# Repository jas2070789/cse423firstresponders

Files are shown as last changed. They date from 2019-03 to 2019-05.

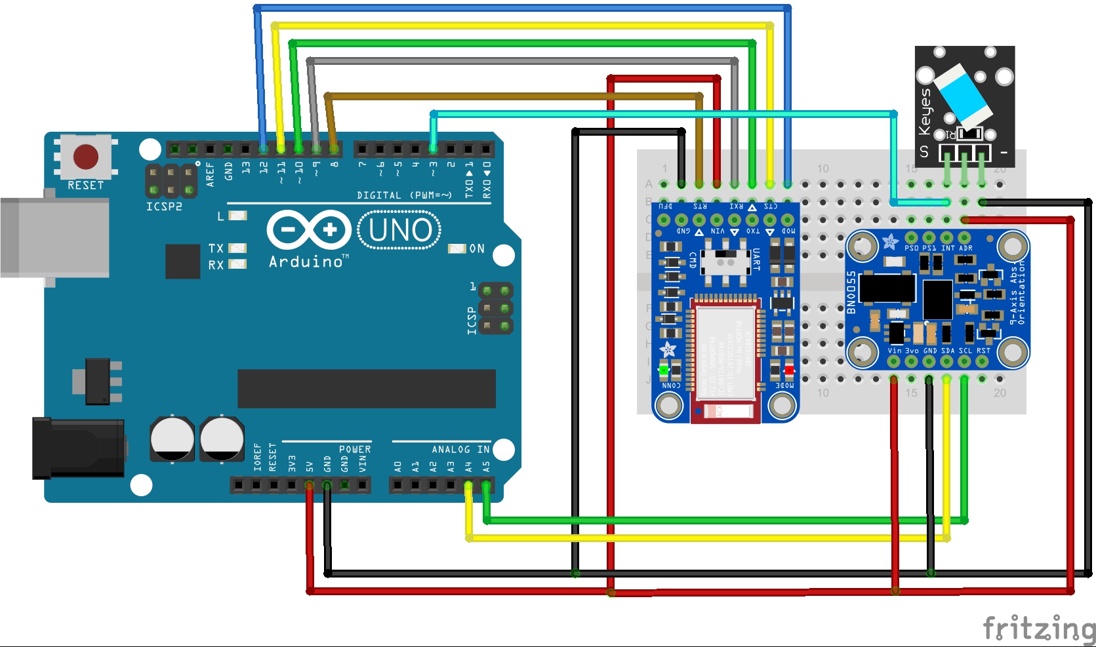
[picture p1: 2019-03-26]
FRONTEND/Wearable_Schematic_bb.jpg

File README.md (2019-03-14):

# CSE423/424 ASU Capstone - Benchmark: First Responder Tracking System
#### Members: Patrick Archer, Joshua Owens, Haoyu Xu, Jason Zellers

## Motivation
Firefighters and first responders commonly experience uncontrolled chaos on their jobs as they rush into dangerous environments to save lives and property. Many frequently navigate buildings and areas with poor visibility and accessibility with little general awareness of their surrounding squadmates. ***Existing methods of tracking firefighter location provide little to no usable or reliable data. This puts firefighters in a great amount of risk.*** Additionally, without real-time knowledge of first responder locations, command central encounters great difficulty in trying to direct personel throughout a scene. For example, directing a squad towards the last known location of a civilian essentially only entails verbal directions via radio. This is not nearly reliable or efficient enough for use by individuals trying to traverse a dangerous environment in a limited amount of time.

***The goal of this project is to provide real-time X, Y, and Z-axis locations for individual on-scene first responders without the use of GPS or an internet connection.***
Improved methods of tracking first responder location would promote safety by providing constant and reliable information regarding individual locations in real-time. Promoting better coordination and teamwork on the job by providing accurate location data would allow first responders to minimize the potential risk to their lives and the lives of civilians in need.

This system is not to be entirely specific to firefighters. It is capable of being utilized by other types of first responders, such as law enforcement and EMS. Coordination and hyper-awareness of every detail on the scene is critical to ensure the safety of everyone involved.  For example, when police or SWAT are actively securing an area, knowledge of the exact count of officials on a scene and where their precise locations are in X,Y, and Z-axes is massively beneficial.

## For more information, please refer to the [Comprehensive Technical Documentation](https://docs.google.com/document/d/1ydmMYP7WzZiBYYO7bbs8z_xTuEj2Cn52D5nfCjR_mMc/edit?usp=sharing).

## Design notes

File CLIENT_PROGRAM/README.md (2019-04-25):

# Overview of "CLIENT" Sub-System

*Note: By default, the Client device needs to use an IPv4 address of ```10.0.2.255``` unless altered otherwise in source code.*

This sub-system encompasses everything required to develop a software program that can 1) join the WADHOC network, 2) query up-to-date location data, and 3) present queried data to a user via a terminal.

After configuring the device to communicate with the WADHOC network, a user will run a custom program that accesses the Central Hub's database. This program utilizes Python socket-level network programming to communicate with the Central Hub and perform database queries via a custom API interface.

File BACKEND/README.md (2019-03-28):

# Overview of "Back-End" Sub-System

The “back-end” sub-system consists of any number Anchor devices, one Central Hub ("CH") device, and a client machine that queries location data from the CH. These devices are all connected to a peer-to-peer Wireless Ad-Hoc network ("WADHOC").

The Anchor nodes communicate with other Anchors as well as the CH via the WADHOC using Python socket shell scripting. 

The CH will process all data incoming from the Anchors, which are constantly forwarding data regarding the Mobile Wearable Beacon ("MWB") devices. Data parsing and calculations are performed entirely by the CH. The CH will act as a single point of access for the most up-to-date location information. As such, the client machine's query program will be directly accessing the CH's database.

The client machine is a laptop ideally running the Ubuntu 18.04 64-bit operating system. This client machine needs to physically be within-range of the WADHOC in order to connect to the network. This is because the CH and Anchor devices are not actually connected to the internet; all communication between devices is entirely local via the WADHOC. The client will use a program to perform data queries. The program will be written in Python v3.0+ with an initial interface in command shell (a GUI may be implemented in a later release). Query data will be in regards to the X, Y, and Z-axis locations of the MWB devices being carried by first responders.

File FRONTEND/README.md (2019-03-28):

# Overview of "Front-End" Sub-System

The front-end sub-system describes the functionality Mobile Wearable Beacon ("MWB") devices alongside the Anchors. The front-end subsystem entirely communicates via Bluetooth-Low-Energy ("BLE"), contrary to the back-end sub-system which communicates via Wireless Ad-Hoc ("WADHOC").

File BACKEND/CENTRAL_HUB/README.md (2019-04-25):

# Overview of "CENTRAL HUB" Sub-System

*Note: By default, the Central Hub device needs to use an IPv4 address of ```10.0.2.1``` unless altered otherwise in source code.*

This sub-system encompasses everything regarding Central Hub operations.

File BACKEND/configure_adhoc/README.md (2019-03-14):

# Configuring a Raspberry Pi's Wireless Network Interface to Connect to WADHOC Network

###### Target Operating System: Raspbian Stretch (Full) v.2018-11-13

***Raspbian Stretch changed much of the networking setups and protocols that were used in previous builds "Wheezy" and "Jessie". As a result, in order to actually set up a Wireless AD-HOC ("WADHOC") network, a few of those changes will need to be bypassed. This README details how to accomplish this.***

For each device that needs to connect to the WADHOC network, `/etc/dhcpcd.conf` and `/etc/network/interfaces` must be modified. When configuring the WADHOC on subsequent devices, the values for certain parameters will need to be changed accordingly. These changes will be discussed in detail further in this document.

*The following information represents what would have to be done to configure the Central Hub device.*

The `/etc/network/interfaces` file has been made obsolete in favor of `/etc/dhcpcd.conf`. However, for a simple ad-hoc network, we have no need to utilize a DHCP server, since the Pis only need to be able to talk to each other. We need to stop the Pi from automatically configuring its wireless interface to its default value. We do that by adding the following command to the top of `/etc/dhcpcd.conf`:

```
denyinterfaces eth0 wlan0
```

*Note: This is assuming the only network interfaces active on the RPi are eth0 and wlan0. If there are more, they must be appended to this command. It is crucial that the wireless interface being used to configure the ad-hoc connection is denied (in this case, wlan0). Use `sudo iwconfig` to query a list of the device's network interfaces. Do not deny the `lo` (loopback) interface.*

The above command tells the RPi that it shouldn’t configure its network interfaces via `/etc/dhcpcd.config` and it should instead configure via `/etc/network/interfaces`.

We then add the following parameters to the `/etc/network/interfaces` file:

```
auto wlan0
iface wlan0 inet static
  address 10.0.0.1
  netmask 255.255.255.0
  wireless-channel 1
  wireless-essid ADHOCTEST
  wireless-mode ad-hoc
```
  
The value for the address will change depending on what node is being configured. 10.0.0.1 will always belong to the Central Hub, however for each Anchor the address needs to be incremented in the /24 subnet (so Anchor1 = 10.0.0.2, A2 = 10.0.0.3, etc.). The netmask, wireless-channel, essid, and mode all remain the same.

After saving the file, restart the device for changes to take full effect. Upon next boot, the device's wlan0 interface will be connected to the "ADHOCTEST" network.

**This process must be repeated for every other node that wants to connect to the WADHOC. The address and (if necessary) the target interface are to be modified, however most other values MUST remain the same (ESSID, channel, netmask, and mode).**

For example, this is what an Anchor device must modify in the two files:

- In /etc/dhcpcd.config:
```
denyinterfaces eth0 wlan0
```

- In /etc/network/interfaces (*note the different address compared to the Central Hub*):
```
auto wlan0
iface wlan0 inet static
  address 10.0.0.2
  netmask 255.255.255.0
  wireless-channel 1
  wireless-essid ADHOCTEST
  wireless-mode ad-hoc
```

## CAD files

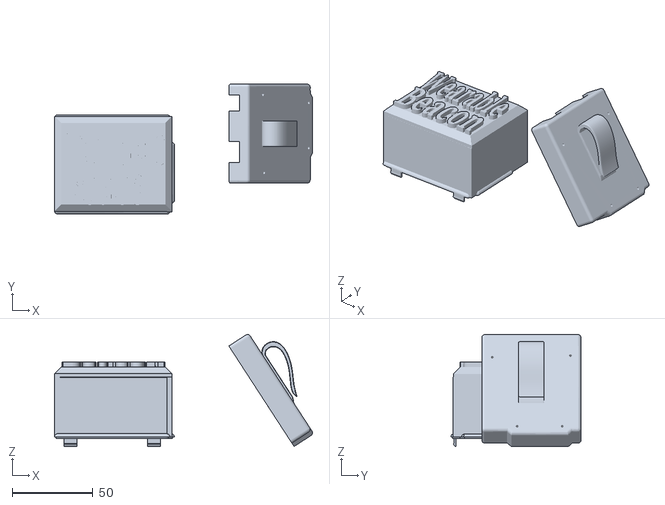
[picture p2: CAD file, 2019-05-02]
FRONTEND/Wearable Bottom Case.stl
159.5 x 80.4 x 69.3

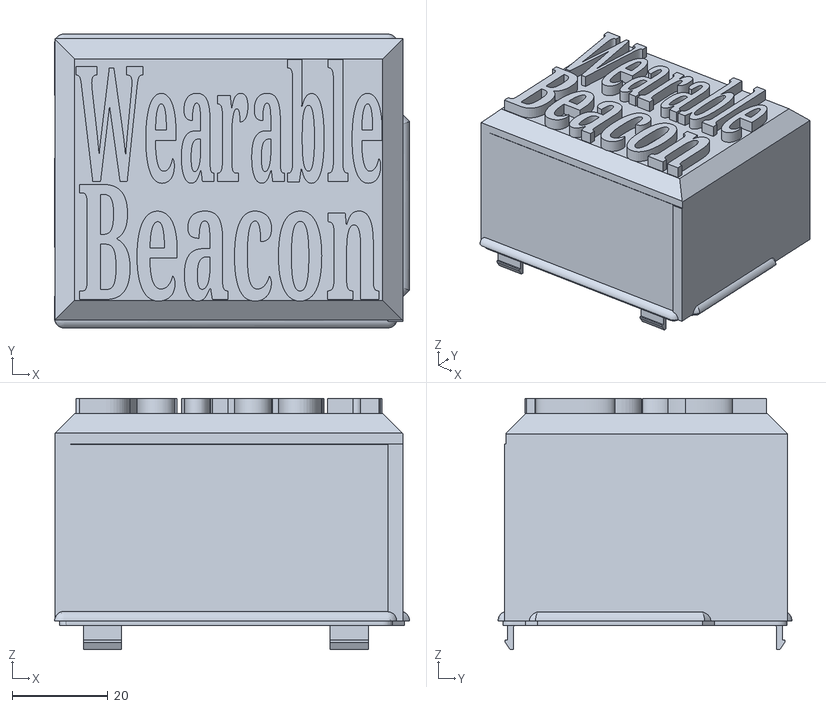
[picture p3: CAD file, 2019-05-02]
FRONTEND/Wearable Top Case/tinker.obj
74.1 x 61.3 x 52.4

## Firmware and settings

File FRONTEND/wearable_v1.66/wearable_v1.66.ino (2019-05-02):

/*
   Connections - BNO055
   ===========
   Connect SCL to analog 5
   Connect SDA to analog 4
   Connect VDD to 3.3V DC
   Connect GROUND to common ground

   Connections - KY-017 - tilt switch
   ===========
   +----------+
   |          |
   |          | - S - D3
   |          | - Power (5v)
   |          | - G - ground
   |          |
   +----------+

   History
   =======
   02/25/19  - V 1.0
   03/21/19  - V 1.5
        Changes:  Added tilt switch
                          Accelorometer from IMU had calibration issues
                  Added quadrant tracking
                  Added pedometer functionality
                  Added string builder (what gets sent over BLE

    03/22/19 - V 1.6
        Changes:  Added BLE Services
                  TODO: Test Services on PI
                  
        TODO:     Add junk calibration validation (if calibration = 0 dont accept data)
                  Add warning light if hard reset is required
                  Verify ArrayFull Functionality
*/

#include <Wire.h>
#include <Adafruit_Sensor.h>
#include <Adafruit_BNO055.h>
#include <utility/imumaths.h>

#include "Adafruit_BLE.h"
#include "Adafruit_BluefruitLE_SPI.h"
#include "Adafruit_BluefruitLE_UART.h"

#include "BluefruitConfig.h"

#if SOFTWARE_SERIAL_AVAILABLE
  #include <SoftwareSerial.h>
#endif

#define BNO055_SAMPLERATE_DELAY_MS (500)
// FROM ONLINE GUID GENERATOR -> define GUIDs for BLE service & characteristic
#define WEARABLE_SERVICE_UUID128  "d9-bd-9b-0e-da-5e-42-de-90-cf-54-5c-7d-17-19-12"
#define WEARABLE_STR_CHAR_UUID128 "45-98-FB-6C-F5-6B-40-28-AD-27-E3-F7-AA-14-89-1F"
#define PACKET_LENGTH 10   // Define the length of a packet (in bytes)   
#define PACKET_ARRAY_LENGTH 50  // Define in multiples of 5                       

Adafruit_BNO055 bno = Adafruit_BNO055(55);

/********************************************************************/
float heading = 0;
int quad = 0; // break 360 degree heading into 4 quadrants
String imuData; // Map FP compass heading & step count
boolean quadChange = false; // track if the quadrant # has changed -> concat step count to string

// Step Count (Pedometer Variables)
int tiltSwitch = 3; // Tilt Switch Input
int tiltVal = 0; // variable to store tilt input
int tiltOldVal; // tilt last state
int stepCount = 0; // state change iterator

// Quadrant Builder Variable
String empID = "001"; // track employee ID    
String buffPacket;
int oldQuad;  //track state change
int count = 0; // placeholder to iterate through packetBuilder
int packetNumber = 0;   // So the gateway can place packet in correct order within the file

// STRTX() variables
int transmit;          // In order to ensure proper packet data exists within IMU data string
int maxTransmit = 5;
boolean arrayEmpty = false;
boolean transmitSuccess = false;

/* The BLE service information */
int32_t wearServiceId;
int32_t wearStringCharId;
boolean success;
//char buff[PACKET_LENGTH];        // Used to iterate through IMU data and place in <UUID><PacketNum><quad><setCount> sequence
String packetBuilder;
String packetData[PACKET_ARRAY_LENGTH]; // Store IMU data into packets-> iterate through array to send over BLE

SoftwareSerial bluefruitSS = SoftwareSerial(BLUEFRUIT_SWUART_TXD_PIN, BLUEFRUIT_SWUART_RXD_PIN);

Adafruit_BluefruitLE_UART ble(bluefruitSS, BLUEFRUIT_UART_MODE_PIN,
                      BLUEFRUIT_UART_CTS_PIN, BLUEFRUIT_UART_RTS_PIN);



/********************************************************************/

void error(const __FlashStringHelper*err) {
  Serial.println(err);
  while (1);
}

void ReadHeading() { // Output: HEADING
  imu::Vector<3> euler = bno.getVector(Adafruit_BNO055::VECTOR_EULER);
  heading = (float)euler.x();
  heading -= 90; // Adjust for IMU orientation

  if (heading < 0 ) {
    heading = 360 + heading;
  }

  if (heading > 360) {
    heading = heading - 360;
  }
  //Serial.print("Heading: \t");
  //Serial.println(heading);
}

void quadrantBuilder() {
  oldQuad = quad;
  count = 0;
  packetBuilder = empID;
  packetBuilder += "|";
  tiltOldVal = tiltVal;

  if (0 < heading && heading < 90) {
    quad = 1;
  } else if (91 < heading && heading < 180) {
    quad = 2;
  } else if (181 < heading && heading < 270) {
    quad = 3;
  } else if (271 < heading && heading < 360) {
    quad = 4;
  } 

  tiltVal = digitalRead (tiltSwitch) ;// read the switch value
        
  if (tiltVal != tiltOldVal) //Step State changed
  {
    stepCount++;
  }
  
  if (oldQuad != quad) {  //Quadrant state change -> new course detected!
    imuData += oldQuad;
    imuData += "|";
    imuData += stepCount;
    imuData += "|";
    stepCount = 0;

    //build BLE Packet
    Serial.print("Packet Number: ");
    Serial.println(packetNumber);
    packetBuilder += packetNumber;
    packetBuilder += "|";
    packetBuilder += imuData;

    Serial.print("imuData length: ");
    Serial.println(imuData.length());
    // parse through packetbuilder to place in packet array data
    while (imuData.length()>0){
      
      //.getBytes(buff,PACKET_LENGTH)
      String str = packetBuilder.substring(0,PACKET_LENGTH);
      packetData[packetNumber] = str; 
     
      // delete last packet
      packetBuilder = packetBuilder.substring(PACKET_LENGTH);

      // iterate for next packet 
      imuData = imuData.substring(PACKET_LENGTH);
      packetNumber+=1;
      if (packetNumber>PACKET_ARRAY_LENGTH+2){
        fullPacketArray();
      }
      count += PACKET_LENGTH;
    }
  }

    //set BLE packet to array
//    packetData[packetNumber] = buffPacket;

  // Serial.print("Quadrant: \t");
  //Serial.println(imuData);
}

void imuStatus() {
  /* check calibration data for each sensor. */
  uint8_t system, gyro, accel, mag;
  system = gyro = accel = mag = 0;
  bno.getCalibration(&system, &gyro, &accel, &mag);
  Serial.print(F("Calibration: "));
  Serial.print(system, DEC);
  Serial.print(F(" "));
  Serial.print(gyro, DEC);
  Serial.print(F(" "));
  Serial.print(accel, DEC);
  Serial.print(F(" "));
  Serial.println(mag, DEC);
}

//void StrTX(){
//  delay(1000);
// // memset(buff,0,sizeof(buff));    //initialize buffer to 0
//  
////  if (count<str.length()){
////    //str.substring(count,count+PACKET_LENGTH).getBytes(buff,PACKET_LENGTH);
////    Serial.print("Buffer: ");
////    Serial.println(buff);
////    Serial.print("string: ");
////    Serial.println(str);
////
////    setCharacteristic(wearTXCharId, buff);
////    
////  }
//
//    Serial.print("transmit: ");
//    Serial.print(transmit);
//    Serial.print("\tmaxTransmit: ");
//    Serial.println(maxTransmit);
//        Serial.print("\tpacketData: ");
//        Serial.println(packetData[transmit]);
//
//    if (packetData[transmit].length()==0){   //end of data in array
//      Serial.println("empty ARRAY");
//      transmit = 0;
//      maxTransmit = 5;
//      arrayEmpty = true;
//      }
//      
//    if (maxTransmit >= PACKET_ARRAY_LENGTH) {
//      Serial.println("FULL ARRAY");
//      transmit = 0;
//      maxTransmit = 5;
//      int halfArray = floor(0.5*PACKET_ARRAY_LENGTH);
//      int j = halfArray;
//      for (int i = 0; i<halfArray; i++) {
//        packetData[i]=packetData[j];
//        packetData[j]= "";
//        j++;
//      }
//    }  
//    
//    int localCounter = transmit;  
//    while ((localCounter < maxTransmit) && (!arrayEmpty)) {
//          setCharacteristic(wearStringCharId, packetData[localCounter]);
//          localCounter++;
//    }
//    Serial.println("Increment");
//    transmit= transmit+ 5;
//    Serial.println("Increment 2");
//    maxTransmit=maxTransmit+5;
//    arrayEmpty = false;
//    
//    
//}

void StrTX(){
  int localCount=transmit;

  if(packetData[transmit].length() == 0  || packetData[transmit+1].length() == 0 || packetData[transmit+2].length() == 0
                                           || packetData[transmit+3].length() == 0 || packetData[transmit+4].length() == 0){
      arrayEmpty = true;
      transmit=0;
      maxTransmit=5;
      
    }
    
  while((maxTransmit<PACKET_ARRAY_LENGTH) && (!arrayEmpty) && localCount < maxTransmit) {
    Serial.print("localCount: ");
    Serial.println(localCount);
    setCharacteristic(wearStringCharId, packetData[localCount]);
    localCount++;
    transmitSuccess = true;
  }

  if (transmitSuccess) {
    transmit+=5;
    maxTransmit+=5;
  }

  if (maxTransmit >= PACKET_ARRAY_LENGTH+5) {
      fullPacketArray();
  }
  arrayEmpty = false;
  transmitSuccess = false;
  Serial.print("transmit: ");
  Serial.print(transmit);
  Serial.print("\tmaxTransmit: ");
  Serial.println(maxTransmit);
}
void fullPacketArray(){
    Serial.println("FULL ARRAY");
//    int a = 0;
//    for (a=0; a < PACKET_ARRAY_LENGTH; a++) {
//      Serial.println(" ARRAY BEFORE");
//      Serial.print(a);
//      Serial.print(": ");
//      Serial.println(packetData[a]);
//    }
    transmit = 0;
    maxTransmit = 5;
    packetNumber = 0;
    int halfArray = floor(0.5*PACKET_ARRAY_LENGTH);
    int j = halfArray;
    for (int i = 0; i<halfArray; i++) {
      packetData[i]=packetData[j];
      packetData[j]= "";
      j++;
    }

//    int b = 0;
//    for (b=0; b < PACKET_ARRAY_LENGTH; b++) {
//      Serial.println(" ARRAY AFTER");
//      Serial.print(b);
//      Serial.print(": ");
//      Serial.println(packetData[b]);
//    }
}
void setCharacteristic(int32_t charId, String str){
  ble.print(F("AT+GATTCHAR="));
  ble.print(charId,DEC);
  ble.print(F(","));
  ble.println(str);
  if (!ble.waitForOK()){
    Serial.println(F("Failed to get a response"));
  }

 // str = empID + "|";
  
}

/********************************************************************/
void setup() {
  Serial.begin(9600);
  if (!bno.begin())
  {
    /* There was a problem detecting the BNO055 ... check your connections */
    Serial.print("Ooops, no BNO055 detected ... Check your wiring or I2C ADDR!");
    while (1);
  }
  //  imuStatus();
  pinMode (tiltSwitch, INPUT) ;// define the mercury tilt switch sensor output interface

  if ( !ble.begin(VERBOSE_MODE) )
  {
    error(F("Couldn't find Bluefruit, make sure it's in CoMmanD mode & check wiring?"));
  }
  Serial.println( F("OK!") );
   /* Perform a factory reset to make sure everything is in a known state */
  Serial.println(F("Performing a factory reset: "));
  if (! ble.factoryReset() ){
       error(F("Couldn't factory reset"));
  }

  /* Disable command echo from Bluefruit */
  ble.echo(false);

  Serial.println("Requesting Bluefruit info:");
  /* Print Bluefruit information */
  ble.info();

  // this line is particularly required for Flora, but is a good idea
  // anyways for the super long lines ahead!
   ble.setInterCharWriteDelay(5); // 5 ms

  /* Change the device name to make it easier to find */
  Serial.println(F("Setting device name to 'wearable': "));

  if (! ble.sendCommandCheckOK(F("AT+GAPDEVNAME=Wearable")) ) {
    error(F("Could not set device name?"));
  }

  /* Add the Wearable Service definition */
  /* Service ID should be 1 */
  Serial.println(F("Adding the Wearable Service definition (UUID = 0x180D): "));
  success = ble.sendCommandWithIntReply( F("AT+GATTADDSERVICE=UUID128=" WEARABLE_SERVICE_UUID128 ), &wearServiceId);
  if (! success) {
    error(F("Could not add Wearable service"));
  }

  /* Add the Wearable String characteristic */
  /* Chars ID for Measurement should be 1 */
  Serial.println(F("Adding the Wearable String characteristic: "));
  success = ble.sendCommandWithIntReply( F("AT+GATTADDCHAR=UUID128=" WEARABLE_STR_CHAR_UUID128 ", PROPERTIES=0x12, MIN_LEN=1, MAX_LEN=20"), &wearStringCharId);
    if (! success) {
    error(F("Could not add Wearable String characteristic"));
  }
  
  /* Reset the device for the new service setting changes to take effect */
  Serial.print(F("Performing a SW reset (service changes require a reset): "));
  ble.reset();
}

/********************************************************************/

void loop() {

  imuStatus();
  ReadHeading();
  quadrantBuilder();
  StrTX();

 
 // Serial.println(str);


  // imu::Vector<3> euler = bno.getVector(Adafruit_BNO055::VECTOR_MAGNETOMETER);

  // test point
  /* Display the floating point data */
  //  Serial.print("X: ");
  //  Serial.print(euler.x());
  //  Serial.print(" Y: ");
  //  Serial.print(euler.y());
  //  Serial.print(" Z: ");
  //  Serial.println(euler.z());


  delay(BNO055_SAMPLERATE_DELAY_MS);
}

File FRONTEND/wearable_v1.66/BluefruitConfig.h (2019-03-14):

// COMMON SETTINGS
// ----------------------------------------------------------------------------------------------
// These settings are used in both SW UART, HW UART and SPI mode
// ----------------------------------------------------------------------------------------------
#define BUFSIZE                        128   // Size of the read buffer for incoming data
#define VERBOSE_MODE                   true  // If set to 'true' enables debug output


// SOFTWARE UART SETTINGS
// ----------------------------------------------------------------------------------------------
// The following macros declare the pins that will be used for 'SW' serial.
// You should use this option if you are connecting the UART Friend to an UNO
// ----------------------------------------------------------------------------------------------
#define BLUEFRUIT_SWUART_RXD_PIN       9    // Required for software serial!
#define BLUEFRUIT_SWUART_TXD_PIN       10   // Required for software serial!
#define BLUEFRUIT_UART_CTS_PIN         11   // Required for software serial!
#define BLUEFRUIT_UART_RTS_PIN         8   // Optional, set to -1 if unused


// HARDWARE UART SETTINGS
// ----------------------------------------------------------------------------------------------
// The following macros declare the HW serial port you are using. Uncomment
// this line if you are connecting the BLE to Leonardo/Micro or Flora
// ----------------------------------------------------------------------------------------------
#ifdef Serial1    // this makes it not complain on compilation if there's no Serial1
  #define BLUEFRUIT_HWSERIAL_NAME      Serial
#endif


// SHARED UART SETTINGS
// ----------------------------------------------------------------------------------------------
// The following sets the optional Mode pin, its recommended but not required
// ----------------------------------------------------------------------------------------------
#define BLUEFRUIT_UART_MODE_PIN        12    // Set to -1 if unused


// SHARED SPI SETTINGS
// ----------------------------------------------------------------------------------------------
// The following macros declare the pins to use for HW and SW SPI communication.
// SCK, MISO and MOSI should be connected to the HW SPI pins on the Uno when
// using HW SPI.  This should be used with nRF51822 based Bluefruit LE modules
// that use SPI (Bluefruit LE SPI Friend).
// ----------------------------------------------------------------------------------------------
//#define BLUEFRUIT_SPI_CS               8
//#define BLUEFRUIT_SPI_IRQ              7
//#define BLUEFRUIT_SPI_RST              4    // Optional but recommended, set to -1 if unused

// SOFTWARE SPI SETTINGS
// ----------------------------------------------------------------------------------------------
// The following macros declare the pins to use for SW SPI communication.
// This should be used with nRF51822 based Bluefruit LE modules that use SPI
// (Bluefruit LE SPI Friend).
// ----------------------------------------------------------------------------------------------
//#define BLUEFRUIT_SPI_SCK              13
//#define BLUEFRUIT_SPI_MISO             12
//#define BLUEFRUIT_SPI_MOSI             11

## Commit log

2019-03-14 Initial upload of wearable files
    IMU and BLE modules work.
    IMU orientation functions still in progress
    BLE module connects to raspberry PI 3, <using hciscan and getttool to connect>.
2019-03-24 added BLE service
    BLE service/characteristics, Quadrant Tracking via magnetometer, step counter via Tilt Switch (ky-017), TODO: test BLE services on PI & Calibration Data Validation
2019-03-26 latest version of MWB code and schematics
2019-03-28 Initial commit: Client/Server socket files
2019-04-25 Update various BACKEND and CLIENT_PROGRAM files
    v1.0 of socket transmission construction
2019-04-26 Added iteration through IMU data
    the whole imu data string can be sent over multiple packets. Say farewell to the 2kb memory of the arduino uno....
2019-05-02 updated 1.66 & added 3d models
    [Wearable Bottom Case.stl, tinker.obj]
